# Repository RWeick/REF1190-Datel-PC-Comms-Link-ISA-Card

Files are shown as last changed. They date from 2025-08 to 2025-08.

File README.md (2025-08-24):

# REF1190-Datel-PC-Comms-Link-ISA-Card
Everything necessary to produce and use the PC Comms Link ISA Card for use with the PSX, N64, and Saturn cheat devices.

This card was designed for use with the original PSX Gameshark / Action Replay, the Sega Saturn Gameshark / Action Replay, and the [N64 Cheat Development System](https://www.nesworld.com/n64-dateltrainercart.php).

PCB Thickness: 1.6 mm

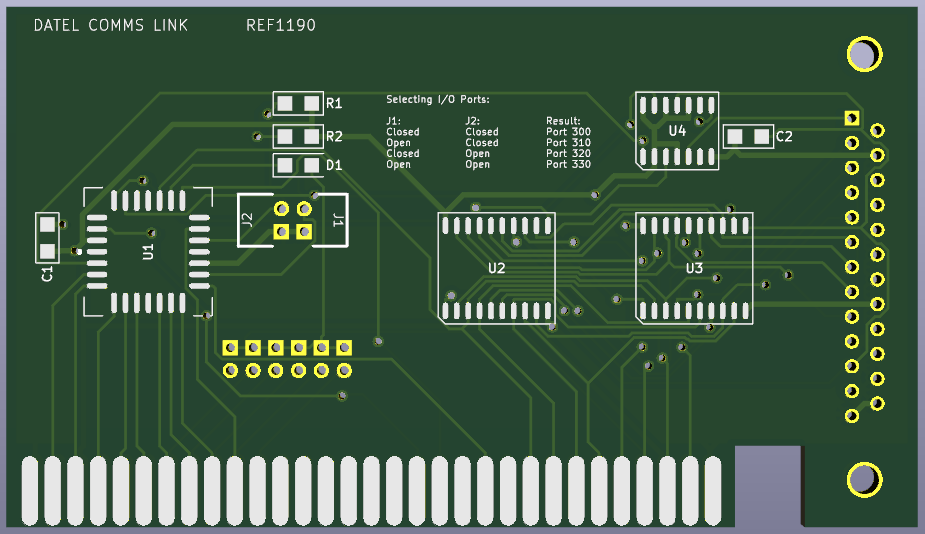
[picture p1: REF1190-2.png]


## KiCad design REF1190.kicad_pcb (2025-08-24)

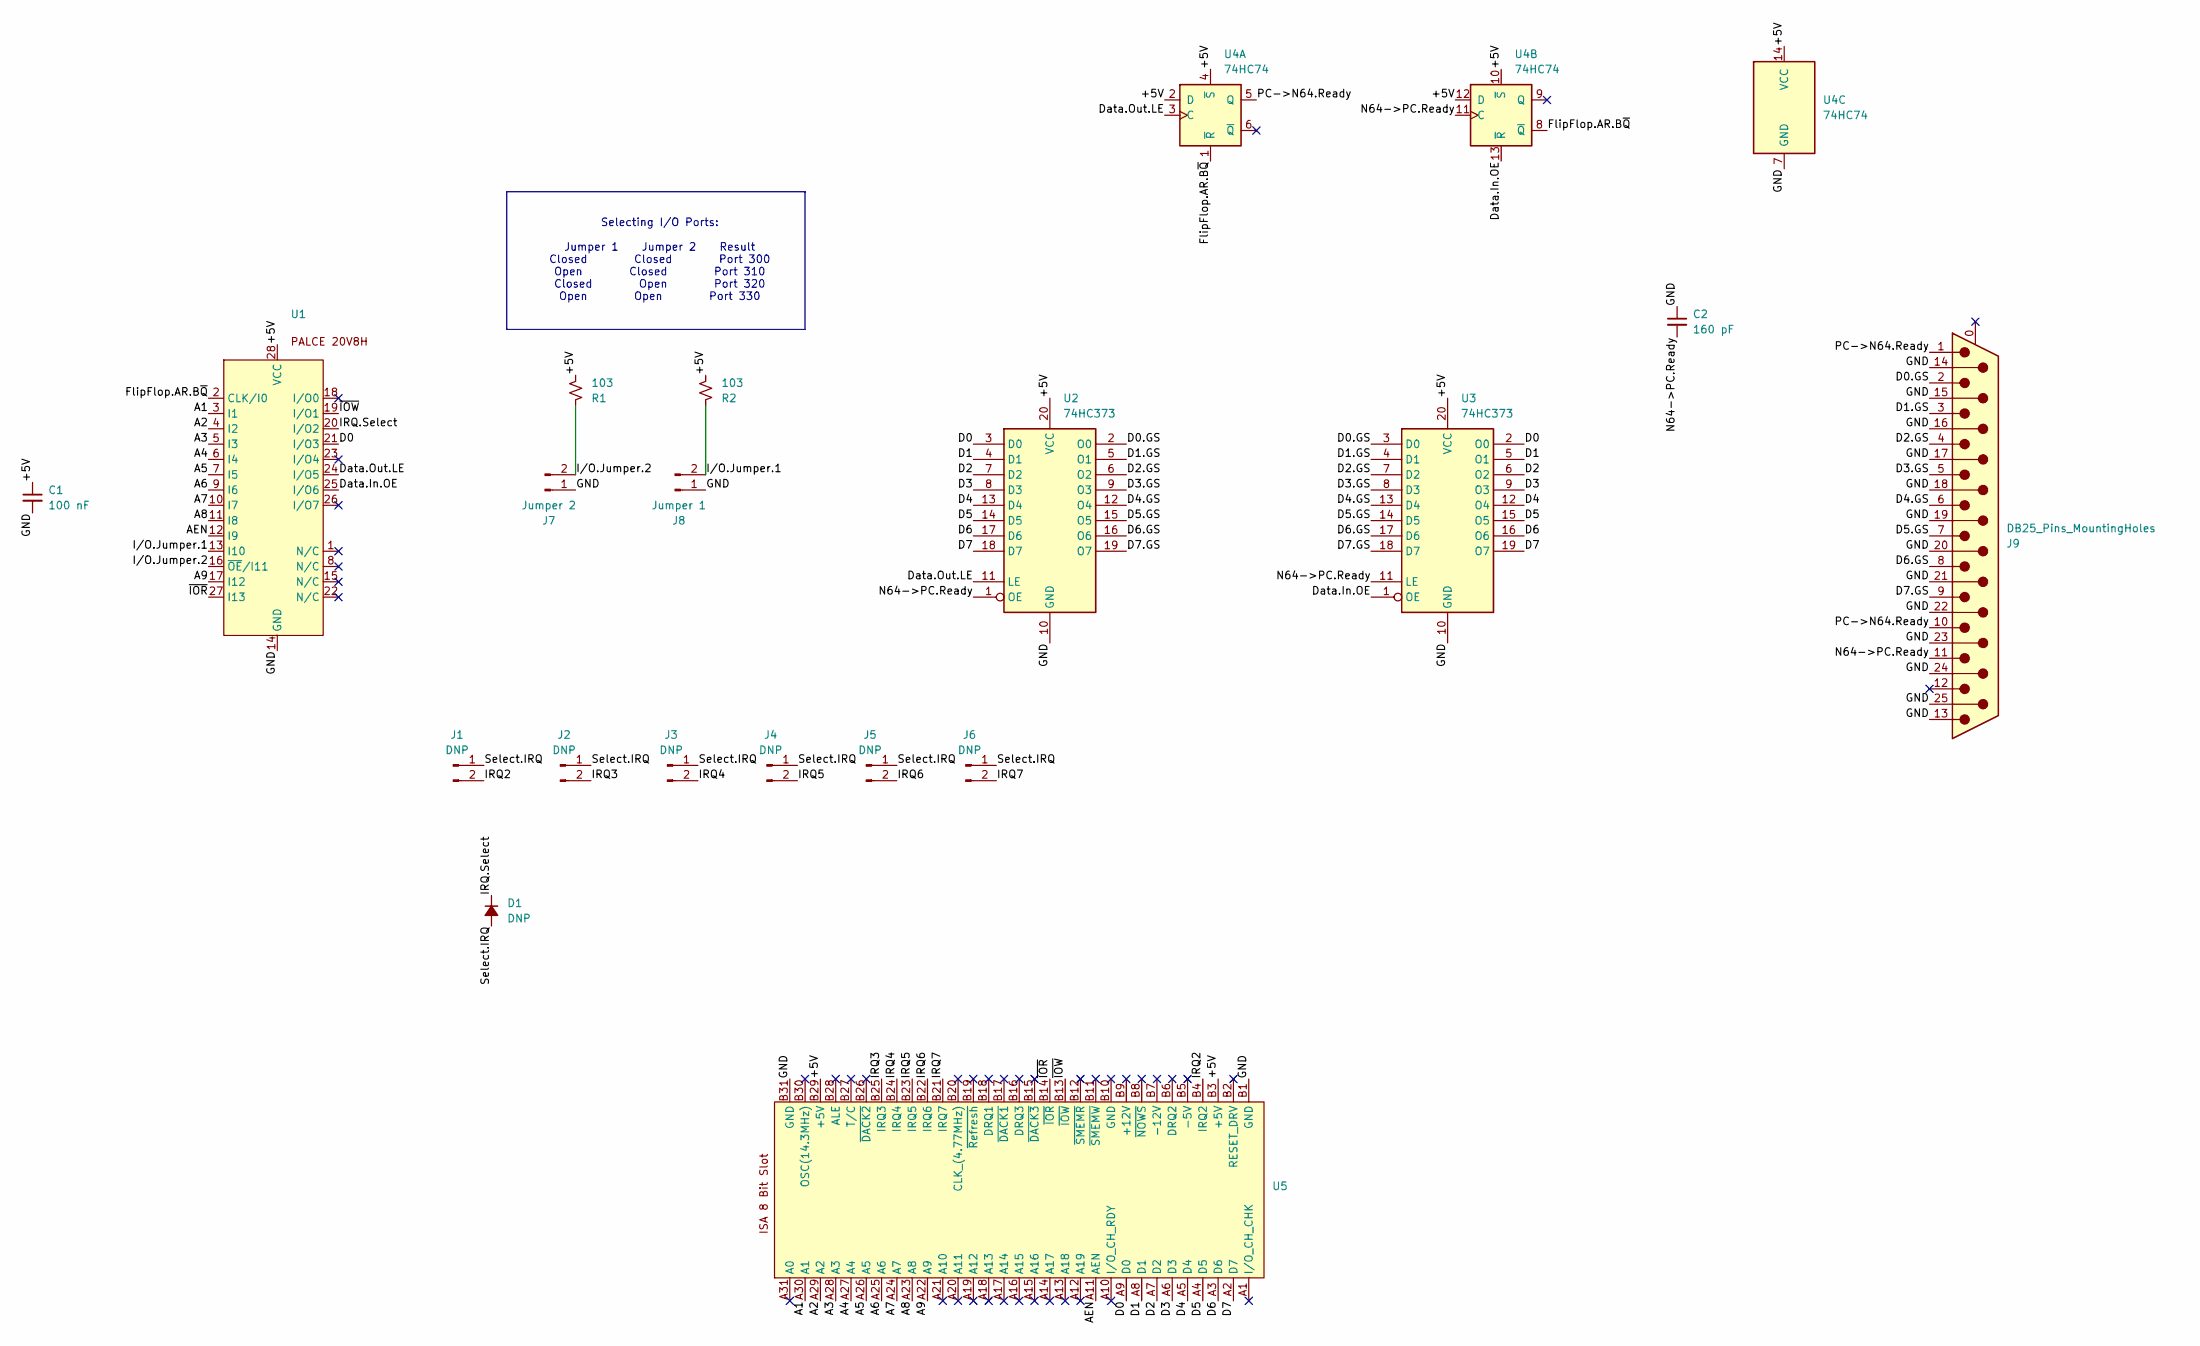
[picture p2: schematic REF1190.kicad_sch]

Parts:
C1: 100 nF; SMD
C2: 160 pF; SMD
D1: DNP
J1, J2, J3, J4, J5, J6: DNP; Jumper
J7: Jumper 2; Jumper
J8: Jumper 1; Jumper
J9: DB25_Pins_MountingHoles; DSUB-25_Socket_Vertical_P2.77x2.84mm_MountingHoles
R1, R2: 103; SMD
U1: PLCC-28
U2, U3: 74HC373; SOIC-20
U4: 74HC74; SOIC-14
U5: ISA Edge Connector

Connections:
/+5V: C1.1, R1.2, R2.2, U1.28 (VCC), U2.20 (VCC), U3.20 (VCC), U4.2 (D), U4.4 (~S), U4.10 (~S), U4.12 (D), U4.14 (VCC), U5.B3 (+5V), U5.B29 (+5V)
/A1: U1.3 (I1), U5.A30 (A1)
/A2: U1.4 (I2), U5.A29 (A2)
/A3: U1.5 (I3), U5.A28 (A3)
/A4: U1.6 (I4), U5.A27 (A4)
/A5: U1.7 (I5), U5.A26 (A5)
/A6: U1.9 (I6), U5.A25 (A6)
/A7: U1.10 (I7), U5.A24 (A7)
/A8: U1.11 (I8), U5.A23 (A8)
/A9: U1.17 (I12), U5.A22 (A9)
/AEN: U1.12 (I9), U5.A11 (AEN)
/D0: U1.21 (I/O3), U2.3 (D0), U3.2 (O0), U5.A9 (D0)
/D0.GS: J9.2, U2.2 (O0), U3.3 (D0)
/D1: U2.4 (D1), U3.5 (O1), U5.A8 (D1)
/D1.GS: J9.3, U2.5 (O1), U3.4 (D1)
/D2: U2.7 (D2), U3.6 (O2), U5.A7 (D2)
/D2.GS: J9.4, U2.6 (O2), U3.7 (D2)
/D3: U2.8 (D3), U3.9 (O3), U5.A6 (D3)
/D3.GS: J9.5, U2.9 (O3), U3.8 (D3)
/D4: U2.13 (D4), U3.12 (O4), U5.A5 (D4)
/D4.GS: J9.6, U2.12 (O4), U3.13 (D4)
/D5: U2.14 (D5), U3.15 (O5), U5.A4 (D5)
/D5.GS: J9.7, U2.15 (O5), U3.14 (D5)
/D6: U2.17 (D6), U3.16 (O6), U5.A3 (D6)
/D6.GS: J9.8, U2.16 (O6), U3.17 (D6)
/D7: U2.18 (D7), U3.19 (O7), U5.A2 (D7)
/D7.GS: J9.9, U2.19 (O7), U3.18 (D7)
/Data.In.OE: U1.25 (I/O6), U3.1 (OE), U4.13 (~R)
/Data.Out.LE: U1.24 (I/O5), U2.11 (LE), U4.3 (C)
/FlipFlop1.Q: J9.1, J9.10, U4.5 (Q)
/FlipFlop.AR.B~Q: U1.2 (CLK/I0), U4.1 (~R), U4.8 (~Q)
/GND: C1.2, C2.1, J7.1, J8.1, J9.13, J9.14, J9.15, J9.16, J9.17, J9.18, J9.19, J9.20, J9.21, J9.22, J9.23, J9.24, J9.25, U1.14 (GND), U2.10 (GND), U3.10 (GND), U4.7 (GND), U5.B1 (GND), U5.B31 (GND)
/IRQ2: J1.2, U5.B4 (IRQ2)
/IRQ3: J2.2, U5.B25 (IRQ3)
/IRQ4: J3.2, U5.B24 (IRQ4)
/IRQ5: J4.2, U5.B23 (IRQ5)
/IRQ6: J5.2, U5.B22 (IRQ6)
/IRQ7: J6.2, U5.B21 (IRQ7)
/IRQ.Select: D1.1 (K), U1.20 (I/O2)
/I/O.Jumper.1: J8.2, R2.1, U1.13 (I10)
/I/O.Jumper.2: J7.2, R1.1, U1.16 (~OE/I11)
/Latch1.OE.2LE: C2.2, J9.11, U2.1 (OE), U3.11 (LE), U4.11 (C)
/Select.IRQ: D1.2 (A), J1.1, J2.1, J3.1, J4.1, J5.1, J6.1
/~IOR: U1.27 (I13), U5.B14 (~IOR)
/~IOW: U1.19 (I/O1), U5.B13 (~IOW)

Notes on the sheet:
Selecting I/O Ports: Jumper 1 Jumper 2 Result Closed Closed Port 300 Open Closed Port 310 Closed Open Port 320 Open Open Port 330

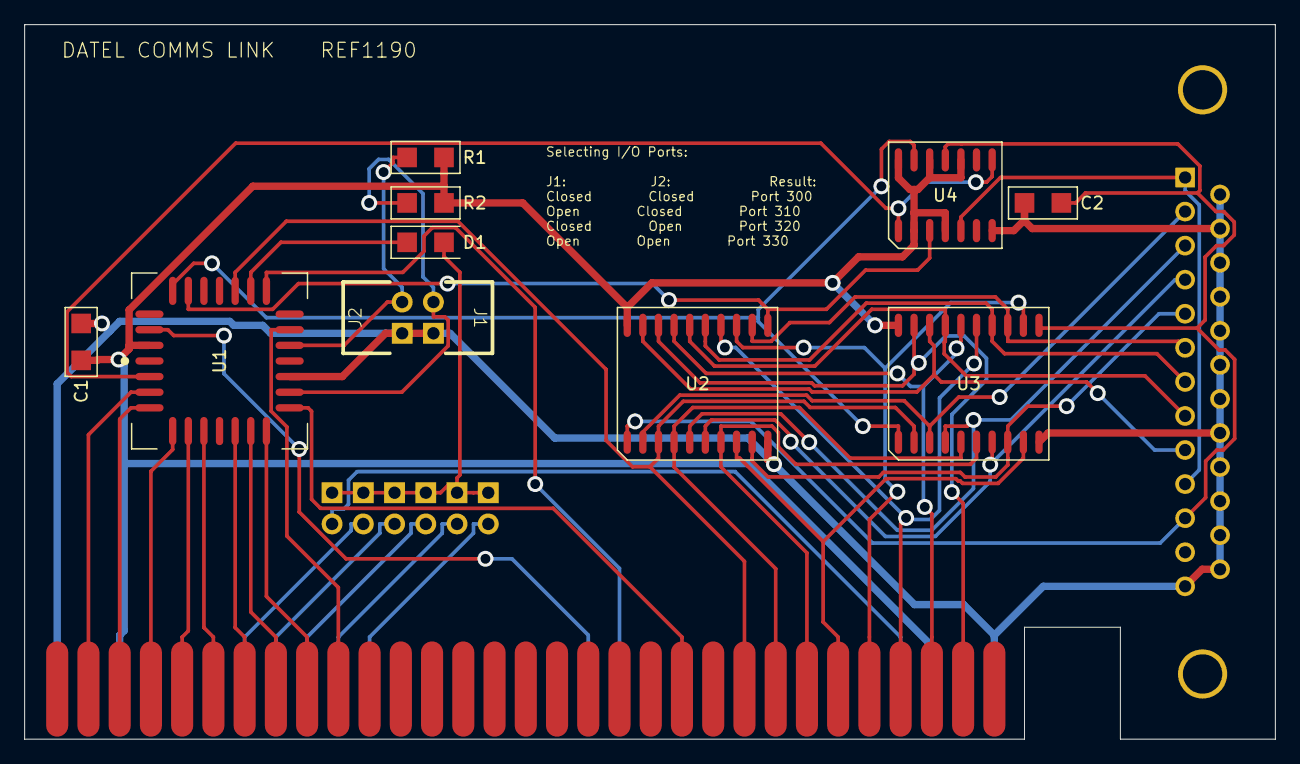
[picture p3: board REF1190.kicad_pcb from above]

Board: 2 copper layers, 101.7 x 58.1 mm, 19 parts (0 on the bottom side), 45 nets.
